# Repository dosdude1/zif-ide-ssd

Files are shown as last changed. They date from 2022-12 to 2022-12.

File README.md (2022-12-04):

# ZIF IDE SSD

A custom-designed IDE SSD for use in any machine that utilizies a 1.8" ZIF IDE hard disk. 

The design is based on the Silicon Motion SM2236 controller, and is compatible with up to four 512Gbit (64GB) BGA152 or BGA132 NANDs.

## Important Info

WARNING: THE SILICON MOTION SM2236 CONTROLLER PINOUT AND IMPLEMENTATION HAVE BEEN REVERSE ENGINEERED FROM OPEN DOCUMENTS AND SALVAGED PCBS, ALL OF WHICH HAVE BEEN LEGALLY OBTAINED. DO NOT EXPECT THIS TO BE CORRECT, CHECK FOR YOURSELF.

### NAND Info

- The NAND ICs used on this PCB must be explicitly supported by the SM2236 controller. All supported NAND ICs are listed in the SM2236 MPTool, or "Mass Production Tool". Be sure to verify compatibility before installing NANDs.

- All installed NAND ICs must match.

- Check the datasheet for your desired NAND ICs to determine their rated I/O voltage, and populate the correct resistor position on the board to set either 3.3V or 1.8V. This is shown in the schematic diagram.

## Programming

Upon the completion of board assembly, the SM2236 controller must be programmed for the NAND ICs you have installed. To do so, you must utilize an IDE to USB adapter to connect the drive to a PC running Windows (using native IDE for this will not work). Then, the SM2236 MPTool must be used to set all the desired drive information, select the part number of NAND ICs you have installed, and program the drive.

## 3D Printed Case

In the `Case` directory you will find an OpenSCAD file to produce a case for the SSD. This has been tuned to prusaslicer with:

- PETG filament

- Monotonic solid infill

- 0.35mm layer height

- 3 perimiters

It has not been printed under any other conditions. Because the case is only 8 layers thick it is very susceptible to poor bed adhesion and warping.

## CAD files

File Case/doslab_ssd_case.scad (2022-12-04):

// Created By: LogoiLab
// https://doslabelectronics.com/
// https://github.com/LogoiLab
// LICENSE: GPL-3.0
// UNITS: mm
$fn = $preview ? 32 : 100;

$board_thickness = 1;
$board_width = 50;
$board_height = 68;
$case_width = 54;
$case_height = 71;
$case_thickness = 5;
$top_components_thickness = 1.32;
$bottom_components_thickness = 0.5;
total_board_thickness = $board_thickness + $top_components_thickness + $bottom_components_thickness + 0.8;
//total_board_thickness = 2.7;

echo(total_board_thickness);

body(true);
translate([55,0,0]) rotate([180,0,0]) body(false);

module body(main) {
    difference() {
        translate([0,0,0]) cube([$case_width, $case_height, $case_thickness], center = true);
        if(main) {
            translate([0,0,($case_thickness/2)]) cube([$case_width, $case_height, $case_thickness], center = true);
            //chamfer();
        } else {
            //rotate([0,180,0]) chamfer();
            translate([0,0,-($case_thickness/2)+1]) cube([$case_width, $case_height, $case_thickness], center = true);
            translate([1,32,0]) cube([23.5,8,10], center=true);
            translate([17,31.5,3]) #cylinder(4,1,1, center=true);
        }
        pcb();
        //scale([1.01,1.01,1]) translate([0,1.3,0]) linear_extrude(height = total_board_thickness, convexity = 10, center = true) import ("./IDE-SSD-ZIF-brd.svg", center = true);
        if (main) {
            holes(total_board_thickness);
        } else {
            holes(total_board_thickness * 3);
        }
    }
}

module holes(depth) {
    translate([24.5,28,0]) #cylinder(depth,0.75,0.75,center=true);
    rotate([0,180,0]) {
        translate([24.5,28,0]) #cylinder(depth,0.75,0.75,center=true);
    }
    translate([0,2,0]) rotate([180,0,0]) {
        translate([24.5,27.5,0]) #cylinder(depth,0.7,0.75,center=true);
        rotate([0,180,0]) {
            translate([24.5,27.5,0]) #cylinder(depth,0.75,0.75,center=true);
        }
    }
}

module chamfer() {
    translate([-($case_width/2) + 1,0,0]) difference() {
        cube([2, $case_height, $case_thickness], center = true);
        translate([0,0,1]) cube([$case_width, $case_height, $case_thickness], center = true);
    }
    translate([$case_width/2 - 1,0,0]) difference() {
        cube([2, $case_height, $case_thickness], center = true);
        translate([0,0,1]) cube([$case_width, $case_height, $case_thickness], center = true);
    }
}

module pcb() {
    difference() {
        union() {
        cube([$board_width,$board_height,total_board_thickness], center=true);
        translate([1,3,0]) cube([23.5,$board_height+3,total_board_thickness], center=true);
        }
        translate([24.5,28,0]) cube([3,3,total_board_thickness],center=true);
        rotate([0,180,0]) {
            translate([24.5,28,0]) cube([3,3,total_board_thickness],center=true);
        }
        translate([0,2,0]) rotate([180,0,0]) {
            translate([24.5,27.5,0]) cube([3,3,total_board_thickness],center=true);
            rotate([0,180,0]) {
                translate([24.5,27.5,0]) cube([3,3,total_board_thickness],center=true);
            }
        }
    }
}

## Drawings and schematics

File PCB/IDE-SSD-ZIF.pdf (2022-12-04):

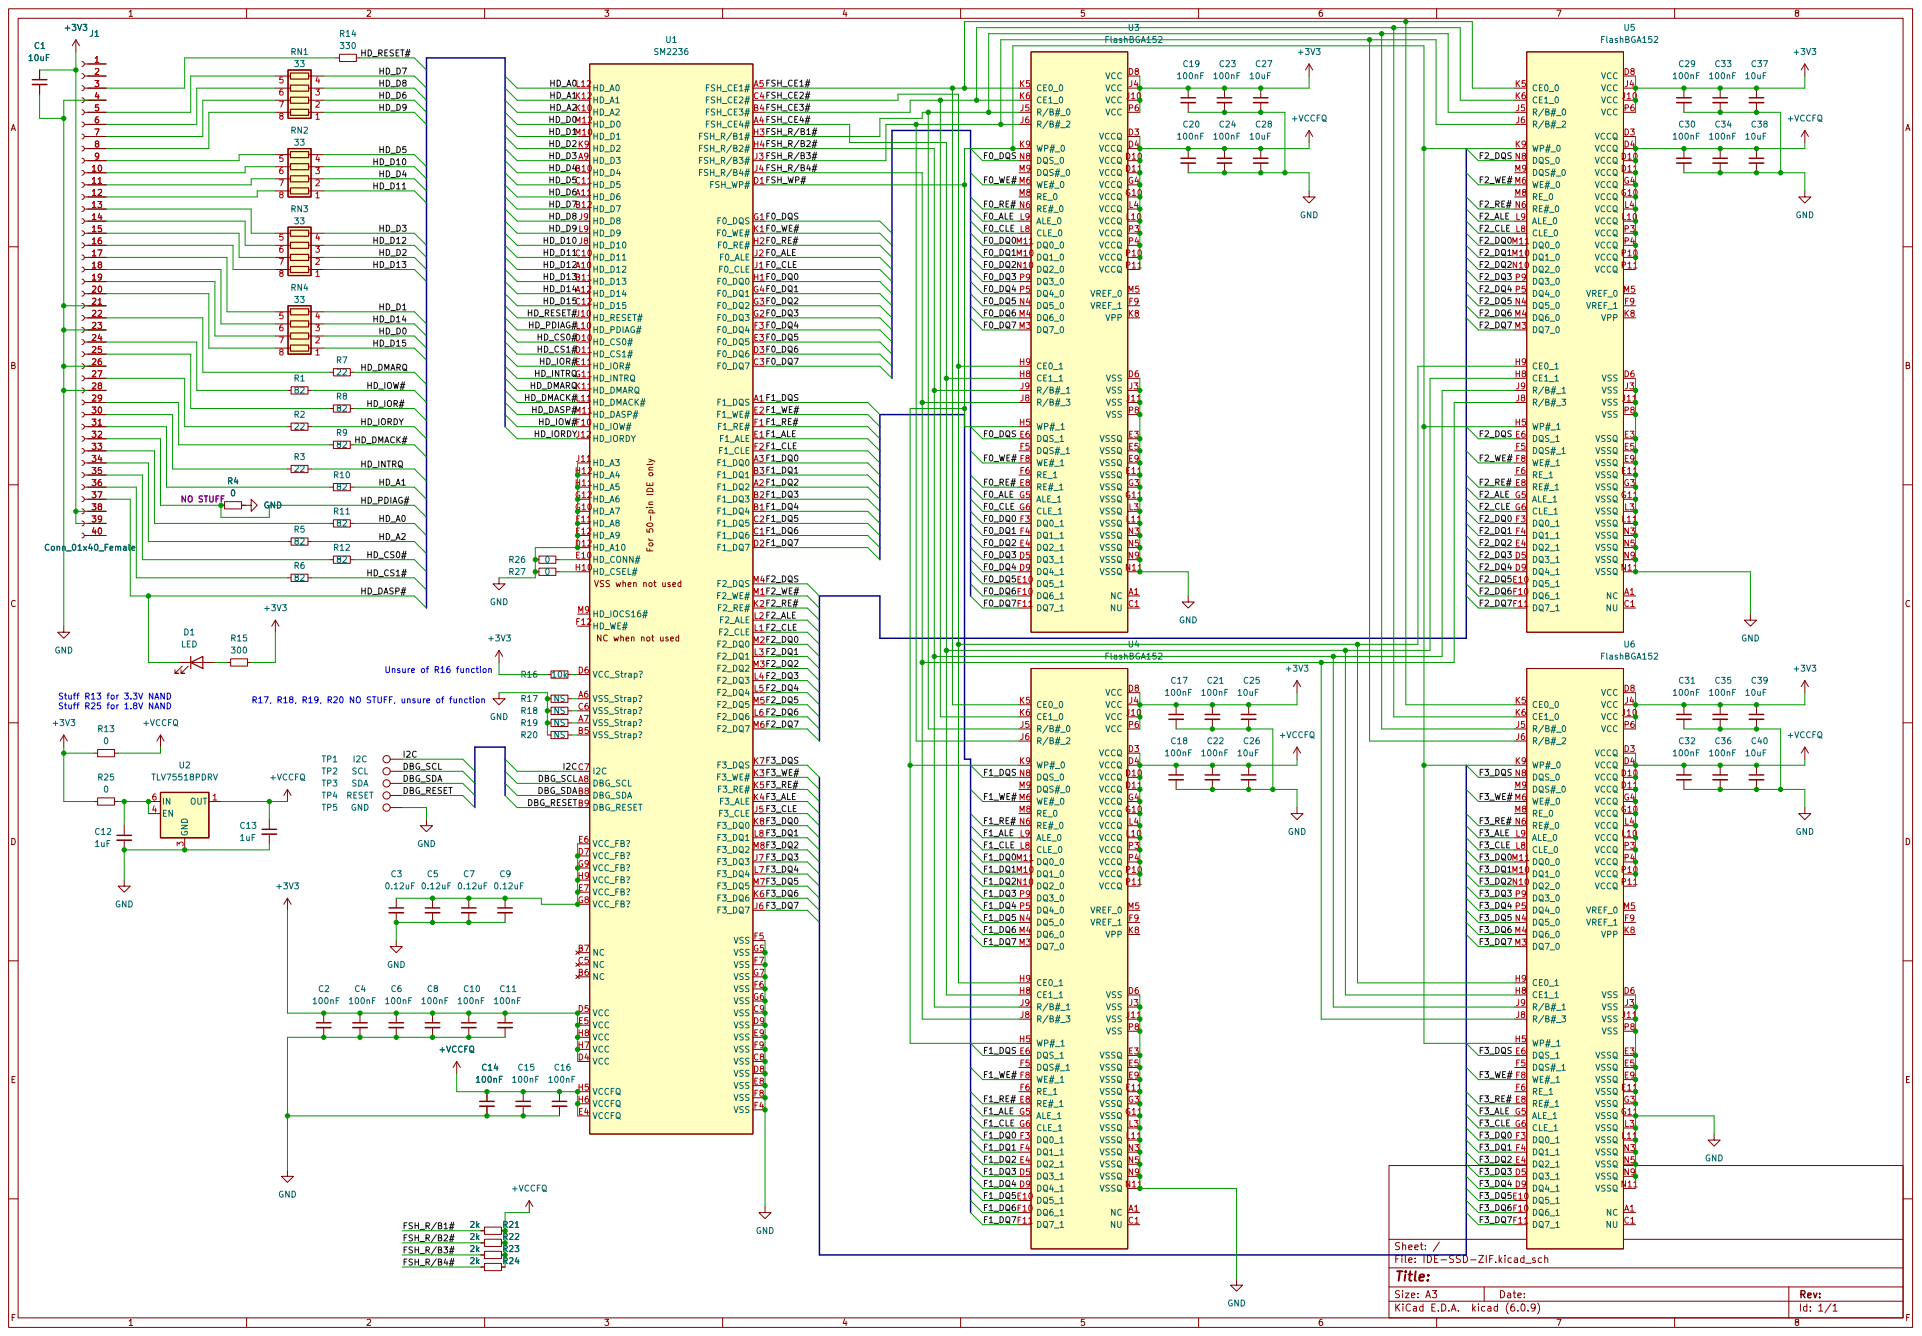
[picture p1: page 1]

File: IDE-SSD-ZIF.kicad_sch Sheet: / GND

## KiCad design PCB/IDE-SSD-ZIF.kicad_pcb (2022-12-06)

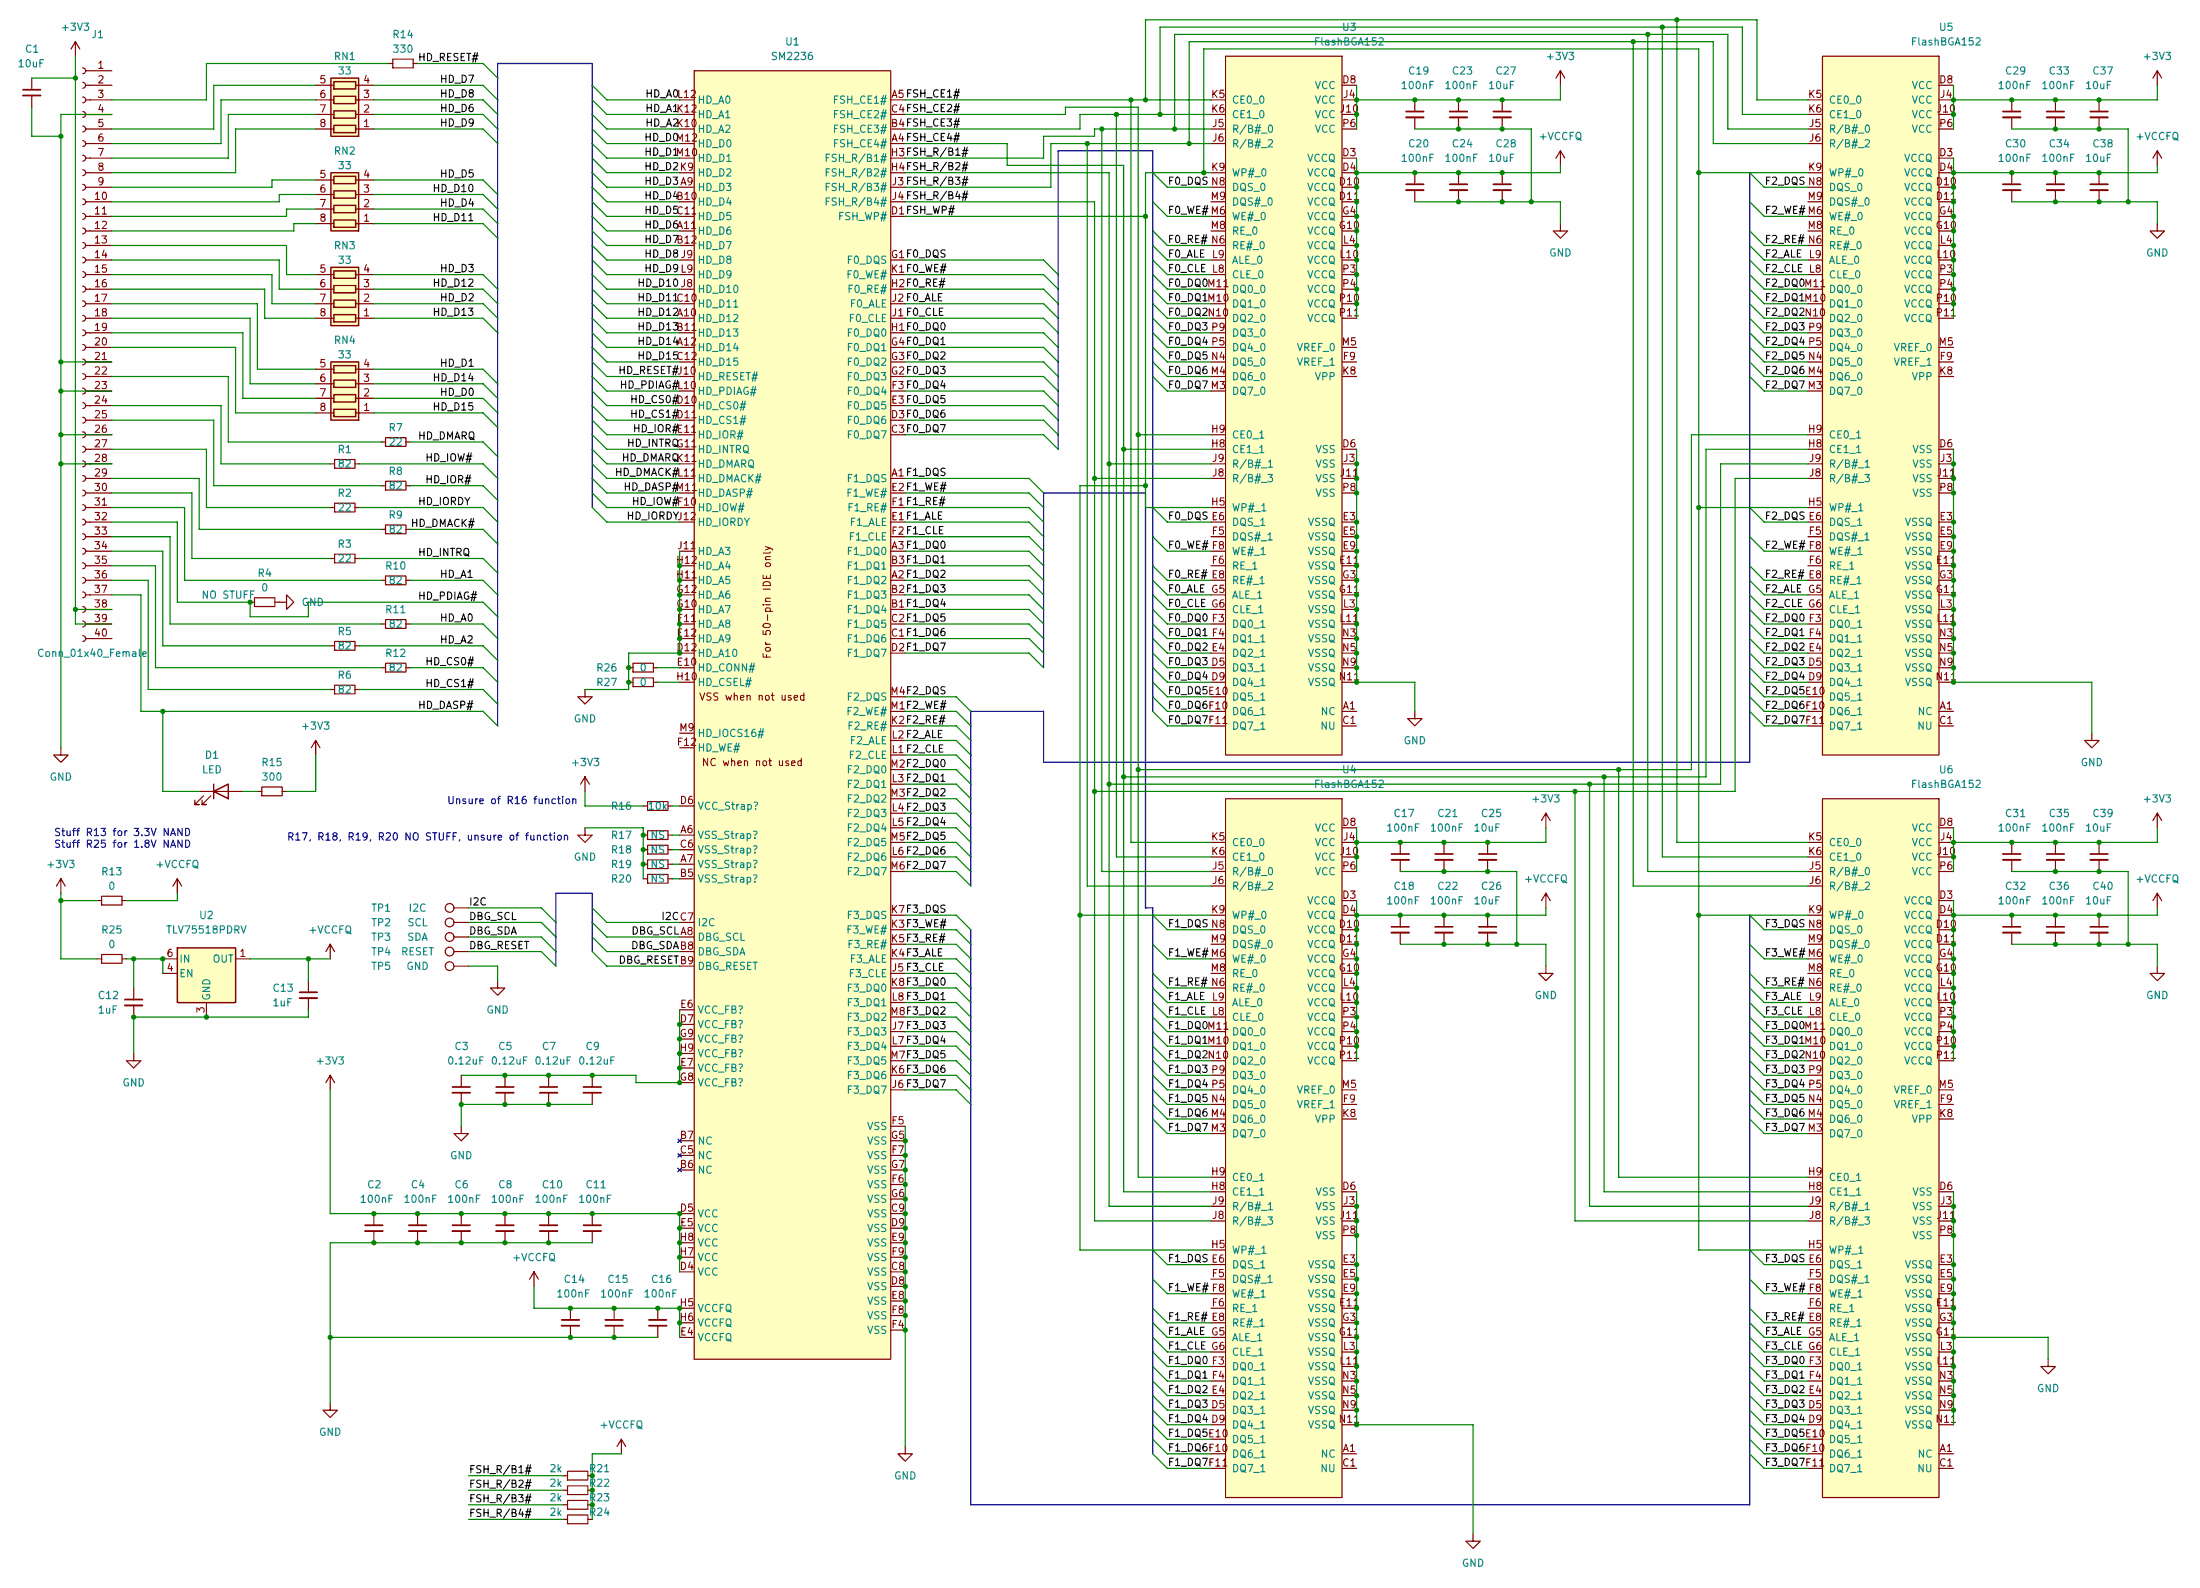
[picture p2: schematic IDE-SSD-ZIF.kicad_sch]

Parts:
C1: 10uF; C_0805_2012Metric
C2, C4, C6, C8, C10, C11, C14, C15, C16, C17, C18, C19, C20, C21, C22, C23, C24, C29, C30, C31, C32, C33, C34, C35, C36: 100nF; C_0402_1005Metric
C3, C5, C7, C9: 0.12uF; C_0402_1005Metric
C12, C13: 1uF; C_0603_1608Metric
C25, C26, C27, C28, C37, C38, C39, C40: 10uF; C_0603_1608Metric
D1: LED; LED_0603_1608Metric
J1: Conn_01x40_Female; OMRON_XF2U-4015-3A
R1, R5, R6, R8, R9, R10, R11, R12: 82; R_0402_1005Metric
R2, R3, R7: 22; R_0402_1005Metric
R4, R26, R27: 0; R_0402_1005Metric
R13, R25: 0; R_0603_1608Metric
R14: 330; R_0402_1005Metric
R15: 300; R_0402_1005Metric
R16: 10k; R_0402_1005Metric
R17, R18, R19, R20: NS; R_0402_1005Metric
R21, R22, R23, R24: 2k; R_0402_1005Metric
RN1, RN2, RN3, RN4: 33; R_Array_Convex_4x0402
TP1: I2C; TestPoint_Pad_1.0x1.0mm
TP2: SCL; TestPoint_Pad_1.0x1.0mm
TP3: SDA; TestPoint_Pad_1.0x1.0mm
TP4: RESET; TestPoint_Pad_1.0x1.0mm
TP5: GND; TestPoint_Pad_1.0x1.0mm
U1: SM2236; BGA-144_12x12_9.0x9.0mm
U2: TLV75518PDRV; WSON-6-1EP_2x2mm_P0.65mm_EP1x1.6mm
U3, U4, U5, U6: FlashBGA152; BGA-152_14x18mm_Layout13x17_P0.5mm

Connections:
+3V3: C1.1, C2.1, C4.1, C6.1, C8.1, C10.1, C11.1, C17.1, C19.1, C21.1, C23.1, C25.1, C27.1, C29.1, C31.1, C33.1, C35.1, C37.1, C39.1, J1.38, J1.39, R13.1, R15.2, R16.1, R25.1, U1.D4 (VCC), U1.D5 (VCC), U1.E5 (VCC), U1.H7 (VCC), U1.H8 (VCC), U3.D8 (VCC), U3.J4 (VCC), U3.J10 (VCC), U3.P6 (VCC), U4.D8 (VCC), U4.J4 (VCC), U4.J10 (VCC), U4.P6 (VCC), U5.D8 (VCC), U5.J4 (VCC), U5.J10 (VCC), U5.P6 (VCC), U6.D8 (VCC), U6.J4 (VCC), U6.J10 (VCC), U6.P6 (VCC)
+VCCFQ: C13.1, C14.1, C15.1, C16.1, C18.1, C20.1, C22.1, C24.1, C26.1, C28.1, C30.1, C32.1, C34.1, C36.1, C38.1, C40.1, R13.2, R21.2, R22.2, R23.2, R24.2, U1.E4 (VCCFQ), U1.H5 (VCCFQ), U1.H6 (VCCFQ), U2.1 (OUT), U3.D3 (VCCQ), U3.D4 (VCCQ), U3.D10 (VCCQ), U3.D11 (VCCQ), U3.G4 (VCCQ), U3.G10 (VCCQ), U3.L4 (VCCQ), U3.L10 (VCCQ), U3.P3 (VCCQ), U3.P4 (VCCQ), U3.P10 (VCCQ), U3.P11 (VCCQ), U4.D3 (VCCQ), U4.D4 (VCCQ), U4.D10 (VCCQ), U4.D11 (VCCQ), U4.G4 (VCCQ), U4.G10 (VCCQ), U4.L4 (VCCQ), U4.L10 (VCCQ), U4.P3 (VCCQ), U4.P4 (VCCQ), U4.P10 (VCCQ), U4.P11 (VCCQ), U5.D3 (VCCQ), U5.D4 (VCCQ), U5.D10 (VCCQ), U5.D11 (VCCQ), U5.G4 (VCCQ), U5.G10 (VCCQ), U5.L4 (VCCQ), U5.L10 (VCCQ), U5.P3 (VCCQ), U5.P4 (VCCQ), U5.P10 (VCCQ), U5.P11 (VCCQ), U6.D3 (VCCQ), U6.D4 (VCCQ), U6.D10 (VCCQ), U6.D11 (VCCQ), U6.G4 (VCCQ), U6.G10 (VCCQ), U6.L4 (VCCQ), U6.L10 (VCCQ), U6.P3 (VCCQ), U6.P4 (VCCQ), U6.P10 (VCCQ), U6.P11 (VCCQ)
/DBG_RESET: TP4.1, U1.B9 (DBG_RESET); also elsewhere on the board
/DBG_SCL: TP2.1, U1.A8 (DBG_SCL); also elsewhere on the board
/DBG_SDA: TP3.1, U1.B8 (DBG_SDA); also elsewhere on the board
/F0_ALE: U1.J2 (F0_ALE), U3.G5 (ALE_1), U3.L9 (ALE_0)
/F0_CLE: U1.J1 (F0_CLE), U3.G6 (CLE_1), U3.L8 (CLE_0)
/F0_DQ0: U1.H1 (F0_DQ0), U3.F3 (DQ0_1), U3.M11 (DQ0_0)
/F0_DQ1: U1.G4 (F0_DQ1), U3.F4 (DQ1_1), U3.M10 (DQ1_0)
/F0_DQ2: U1.G3 (F0_DQ2), U3.E4 (DQ2_1), U3.N10 (DQ2_0)
/F0_DQ3: U1.G2 (F0_DQ3), U3.D5 (DQ3_1), U3.P9 (DQ3_0)
/F0_DQ4: U1.F3 (F0_DQ4), U3.D9 (DQ4_1), U3.P5 (DQ4_0)
/F0_DQ5: U1.E3 (F0_DQ5), U3.E10 (DQ5_1), U3.N4 (DQ5_0)
/F0_DQ6: U1.D3 (F0_DQ6), U3.F10 (DQ6_1), U3.M4 (DQ6_0)
/F0_DQ7: U1.C3 (F0_DQ7), U3.F11 (DQ7_1), U3.M3 (DQ7_0)
/F0_DQS: U1.G1 (F0_DQS), U3.E6 (DQS_1), U3.N8 (DQS_0)
/F0_RE#: U1.H2 (F0_RE#), U3.E8 (RE#_1), U3.N6 (RE#_0)
/F0_WE#: U1.K1 (F0_WE#), U3.F8 (WE#_1), U3.M6 (WE#_0)
/F1_ALE: U1.E1 (F1_ALE), U4.G5 (ALE_1), U4.L9 (ALE_0)
/F1_CLE: U1.F2 (F1_CLE), U4.G6 (CLE_1), U4.L8 (CLE_0)
/F1_DQ0: U1.A3 (F1_DQ0), U4.F3 (DQ0_1), U4.M11 (DQ0_0)
/F1_DQ1: U1.B3 (F1_DQ1), U4.F4 (DQ1_1), U4.M10 (DQ1_0)
/F1_DQ2: U1.A2 (F1_DQ2), U4.E4 (DQ2_1), U4.N10 (DQ2_0)
/F1_DQ3: U1.B2 (F1_DQ3), U4.D5 (DQ3_1), U4.P9 (DQ3_0)
/F1_DQ4: U1.B1 (F1_DQ4), U4.D9 (DQ4_1), U4.P5 (DQ4_0)
/F1_DQ5: U1.C2 (F1_DQ5), U4.E10 (DQ5_1), U4.N4 (DQ5_0)
/F1_DQ6: U1.C1 (F1_DQ6), U4.F10 (DQ6_1), U4.M4 (DQ6_0)
/F1_DQ7: U1.D2 (F1_DQ7), U4.F11 (DQ7_1), U4.M3 (DQ7_0)
/F1_DQS: U1.A1 (F1_DQS), U4.E6 (DQS_1), U4.N8 (DQS_0)
/F1_RE#: U1.F1 (F1_RE#), U4.E8 (RE#_1), U4.N6 (RE#_0)
/F1_WE#: U1.E2 (F1_WE#), U4.F8 (WE#_1), U4.M6 (WE#_0)
/F2_ALE: U1.L2 (F2_ALE), U5.G5 (ALE_1), U5.L9 (ALE_0)
/F2_CLE: U1.L1 (F2_CLE), U5.G6 (CLE_1), U5.L8 (CLE_0)
/F2_DQ0: U1.M2 (F2_DQ0), U5.F3 (DQ0_1), U5.M11 (DQ0_0)
/F2_DQ1: U1.L3 (F2_DQ1), U5.F4 (DQ1_1), U5.M10 (DQ1_0)
/F2_DQ2: U1.M3 (F2_DQ2), U5.E4 (DQ2_1), U5.N10 (DQ2_0)
/F2_DQ3: U1.L4 (F2_DQ3), U5.D5 (DQ3_1), U5.P9 (DQ3_0)
/F2_DQ4: U1.L5 (F2_DQ4), U5.D9 (DQ4_1), U5.P5 (DQ4_0)
/F2_DQ5: U1.M5 (F2_DQ5), U5.E10 (DQ5_1), U5.N4 (DQ5_0)
/F2_DQ6: U1.L6 (F2_DQ6), U5.F10 (DQ6_1), U5.M4 (DQ6_0)
/F2_DQ7: U1.M6 (F2_DQ7), U5.F11 (DQ7_1), U5.M3 (DQ7_0)
/F2_DQS: U1.M4 (F2_DQS), U5.E6 (DQS_1), U5.N8 (DQS_0)
/F2_RE#: U1.K2 (F2_RE#), U5.E8 (RE#_1), U5.N6 (RE#_0)
/F2_WE#: U1.M1 (F2_WE#), U5.F8 (WE#_1), U5.M6 (WE#_0)
/F3_ALE: U1.K4 (F3_ALE), U6.G5 (ALE_1), U6.L9 (ALE_0)
/F3_CLE: U1.J5 (F3_CLE), U6.G6 (CLE_1), U6.L8 (CLE_0)
/F3_DQ0: U1.K8 (F3_DQ0), U6.F3 (DQ0_1), U6.M11 (DQ0_0)
/F3_DQ1: U1.L8 (F3_DQ1), U6.F4 (DQ1_1), U6.M10 (DQ1_0)
/F3_DQ2: U1.M8 (F3_DQ2), U6.E4 (DQ2_1), U6.N10 (DQ2_0)
/F3_DQ3: U1.J7 (F3_DQ3), U6.D5 (DQ3_1), U6.P9 (DQ3_0)
/F3_DQ4: U1.L7 (F3_DQ4), U6.D9 (DQ4_1), U6.P5 (DQ4_0)
/F3_DQ5: U1.M7 (F3_DQ5), U6.E10 (DQ5_1), U6.N4 (DQ5_0)
/F3_DQ6: U1.K6 (F3_DQ6), U6.F10 (DQ6_1), U6.M4 (DQ6_0)
/F3_DQ7: U1.J6 (F3_DQ7), U6.F11 (DQ7_1), U6.M3 (DQ7_0)
/F3_DQS: U1.K7 (F3_DQS), U6.E6 (DQS_1), U6.N8 (DQS_0)
/F3_RE#: U1.K5 (F3_RE#), U6.E8 (RE#_1), U6.N6 (RE#_0)
/F3_WE#: U1.K3 (F3_WE#), U6.F8 (WE#_1), U6.M6 (WE#_0)
/FSH_CE1#: U1.A5 (FSH_CE1#), U3.K5 (CE0_0), U4.K5 (CE0_0), U5.K5 (CE0_0), U6.K5 (CE0_0)
/FSH_CE2#: U1.C4 (FSH_CE2#), U3.H9 (CE0_1), U4.H9 (CE0_1), U5.H9 (CE0_1), U6.H9 (CE0_1)
/FSH_CE3#: U1.B4 (FSH_CE3#), U3.K6 (CE1_0), U4.K6 (CE1_0), U5.K6 (CE1_0), U6.K6 (CE1_0)
/FSH_CE4#: U1.A4 (FSH_CE4#), U3.H8 (CE1_1), U4.H8 (CE1_1), U5.H8 (CE1_1), U6.H8 (CE1_1)
/FSH_R/B1#: R21.1, U1.H3 (FSH_R/B1#), U3.J5 (R/B#_0), U4.J5 (R/B#_0), U5.J5 (R/B#_0), U6.J5 (R/B#_0)
/FSH_R/B2#: R22.1, U1.H4 (FSH_R/B2#), U3.J9 (R/B#_1), U4.J9 (R/B#_1), U5.J9 (R/B#_1), U6.J9 (R/B#_1)
/FSH_R/B3#: R23.1, U1.J3 (FSH_R/B3#), U3.J6 (R/B#_2), U4.J6 (R/B#_2), U5.J6 (R/B#_2), U6.J6 (R/B#_2)
/FSH_R/B4#: R24.1, U1.J4 (FSH_R/B4#), U3.J8 (R/B#_3), U4.J8 (R/B#_3), U5.J8 (R/B#_3), U6.J8 (R/B#_3)
/FSH_WP#: U1.D1 (FSH_WP#), U3.H5 (WP#_1), U3.K9 (WP#_0), U4.H5 (WP#_1), U4.K9 (WP#_0), U5.H5 (WP#_1), U5.K9 (WP#_0), U6.H5 (WP#_1), U6.K9 (WP#_0)
/HD_A0: R11.2, U1.L12 (HD_A0)
/HD_A1: R10.2, U1.K12 (HD_A1)
/HD_A2: R5.2, U1.K10 (HD_A2)
/HD_CS0#: R12.2, U1.D10 (HD_CS0#)
/HD_CS1#: R6.2, U1.D11 (HD_CS1#)
/HD_D0: RN4.2 (R2.1), U1.M12 (HD_D0)
/HD_D1: RN4.4 (R4.1), U1.M10 (HD_D1)
/HD_D2: RN3.2 (R2.1), U1.K9 (HD_D2)
/HD_D3: RN3.4 (R4.1), U1.A9 (HD_D3)
/HD_D4: RN2.2 (R2.1), U1.B10 (HD_D4)
/HD_D5: RN2.4 (R4.1), U1.C11 (HD_D5)
/HD_D6: RN1.2 (R2.1), U1.A11 (HD_D6)
/HD_D7: RN1.4 (R4.1), U1.B12 (HD_D7)
/HD_D8: RN1.3 (R3.1), U1.J9 (HD_D8)
/HD_D9: RN1.1 (R1.1), U1.L9 (HD_D9)
/HD_D10: RN2.3 (R3.1), U1.J8 (HD_D10)
/HD_D11: RN2.1 (R1.1), U1.C10 (HD_D11)
/HD_D12: RN3.3 (R3.1), U1.A10 (HD_D12)
/HD_D13: RN3.1 (R1.1), U1.B11 (HD_D13)
/HD_D14: RN4.3 (R3.1), U1.A12 (HD_D14)
/HD_D15: RN4.1 (R1.1), U1.C12 (HD_D15)
/HD_DASP#: D1.1 (K), J1.37, U1.M11 (HD_DASP#)
/HD_DMACK#: R9.2, U1.L11 (HD_DMACK#)
/HD_DMARQ: R7.2, U1.K11 (HD_DMARQ)
/HD_INTRQ: R3.2, U1.G11 (HD_INTRQ)
/HD_IOR#: R8.2, U1.E11 (HD_IOR#)
/HD_IORDY: R2.2, U1.J12 (HD_IORDY)
/HD_IOW#: R1.2, U1.F10 (HD_IOW#)
/HD_PDIAG#: J1.32, R4.1, U1.L10 (HD_PDIAG#)
/HD_RESET#: R14.2, U1.J10 (HD_RESET#)
/I2C: TP1.1, U1.C7 (I2C); also elsewhere on the board
GND: C1.2, C2.2, C3.2, C4.2, C5.2, C6.2, C7.2, C8.2, C9.2, C10.2, C11.2, C12.2, C13.2, C14.2, C15.2, C16.2, C17.2, C18.2, C19.2, C20.2, C21.2, C22.2, C23.2, C24.2, C25.2, C26.2, C27.2, C28.2, C29.2, C30.2, C31.2, C32.2, C33.2, C34.2, C35.2, C36.2, C37.2, C38.2, C39.2, C40.2, J1.4, J1.21, J1.23, J1.26, J1.28, R4.2, R17.1, R18.1, R19.1, R20.1, R26.1, R27.1, TP5.1, U1.C8 (VSS), U1.C9 (VSS), U1.D8 (VSS), U1.D9 (VSS), U1.D12 (HD_A10), U1.E8 (VSS), U1.E9 (VSS), U1.E12 (HD_A9), U1.F4 (VSS), U1.F5 (VSS), U1.F6 (VSS), U1.F7 (VSS), U1.F8 (VSS), U1.F9 (VSS), U1.F11 (HD_A8), U1.G5 (VSS), U1.G6 (VSS), U1.G7 (VSS), U1.G10 (HD_A7), U1.G12 (HD_A6), U1.H11 (HD_A5), U1.H12 (HD_A4), U1.J11 (HD_A3), U2.3 (GND), U2.7 (GND), U3.D6 (VSS), U3.E3 (VSSQ), U3.E5 (VSSQ), U3.E9 (VSSQ), U3.E11 (VSSQ), U3.G3 (VSSQ), U3.G11 (VSSQ), U3.J3 (VSS), U3.J11 (VSS), U3.L3 (VSSQ), U3.L11 (VSSQ), U3.N3 (VSSQ), U3.N5 (VSSQ), U3.N9 (VSSQ), U3.N11 (VSSQ), U3.P8 (VSS), U4.D6 (VSS), U4.E3 (VSSQ), U4.E5 (VSSQ), U4.E9 (VSSQ), U4.E11 (VSSQ), U4.G3 (VSSQ), U4.G11 (VSSQ), U4.J3 (VSS), U4.J11 (VSS), U4.L3 (VSSQ), U4.L11 (VSSQ), U4.N3 (VSSQ), U4.N5 (VSSQ), U4.N9 (VSSQ), U4.N11 (VSSQ), U4.P8 (VSS), U5.D6 (VSS), U5.E3 (VSSQ), U5.E5 (VSSQ), U5.E9 (VSSQ), U5.E11 (VSSQ), U5.G3 (VSSQ), U5.G11 (VSSQ), U5.J3 (VSS), U5.J11 (VSS), U5.L3 (VSSQ), U5.L11 (VSSQ), U5.N3 (VSSQ), U5.N5 (VSSQ), U5.N9 (VSSQ), U5.N11 (VSSQ), U5.P8 (VSS), U6.D6 (VSS), U6.E3 (VSSQ), U6.E5 (VSSQ), U6.E9 (VSSQ), U6.E11 (VSSQ), U6.G3 (VSSQ), U6.G11 (VSSQ), U6.J3 (VSS), U6.J11 (VSS), U6.L3 (VSSQ), U6.L11 (VSSQ), U6.N3 (VSSQ), U6.N5 (VSSQ), U6.N9 (VSSQ), U6.N11 (VSSQ), U6.P8 (VSS); also elsewhere on the board
unnamed: C3.1, C5.1, C7.1, C9.1, U1.D7 (VCC_FB?), U1.E6 (VCC_FB?), U1.E7 (VCC_FB?), U1.G8 (VCC_FB?), U1.G9 (VCC_FB?), U1.H9 (VCC_FB?)
unnamed: C12.1, R25.2, U2.4 (EN), U2.6 (IN)
unnamed: D1.2 (A), R15.1
unnamed: J1.3, R14.1
unnamed: J1.5, RN1.5 (R4.2)
unnamed: J1.6, RN1.6 (R3.2)
unnamed: J1.7, RN1.7 (R2.2)
unnamed: J1.8, RN1.8 (R1.2)
unnamed: J1.9, RN2.5 (R4.2)
unnamed: J1.10, RN2.6 (R3.2)
unnamed: J1.11, RN2.7 (R2.2)
unnamed: J1.12, RN2.8 (R1.2)
unnamed: J1.13, RN3.5 (R4.2)
unnamed: J1.14, RN3.6 (R3.2)
unnamed: J1.15, RN3.7 (R2.2)
unnamed: J1.16, RN3.8 (R1.2)
unnamed: J1.17, RN4.5 (R4.2)
unnamed: J1.18, RN4.6 (R3.2)
unnamed: J1.19, RN4.7 (R2.2)
unnamed: J1.20, RN4.8 (R1.2)
unnamed: J1.22, R7.1
unnamed: J1.24, R1.1
unnamed: J1.25, R8.1
unnamed: J1.27, R2.1
unnamed: J1.29, R9.1
unnamed: J1.30, R3.1
unnamed: J1.31, R10.1
unnamed: J1.33, R11.1
unnamed: J1.34, R5.1
unnamed: J1.35, R12.1
unnamed: J1.36, R6.1
unnamed: R16.2, U1.D6 (VCC_Strap?)
unnamed: R17.2, U1.A6 (VSS_Strap?)
unnamed: R18.2, U1.C6 (VSS_Strap?)
unnamed: R19.2, U1.A7 (VSS_Strap?)
unnamed: R20.2, U1.B5 (VSS_Strap?)
unnamed: R26.2, U1.E10 (HD_CONN#)
unnamed: R27.2, U1.H10 (HD_CSEL#)

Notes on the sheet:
Stuff R13 for 3.3V NAND Stuff R25 for 1.8V NAND
Unsure of R16 function
R17, R18, R19, R20 NO STUFF, unsure of function

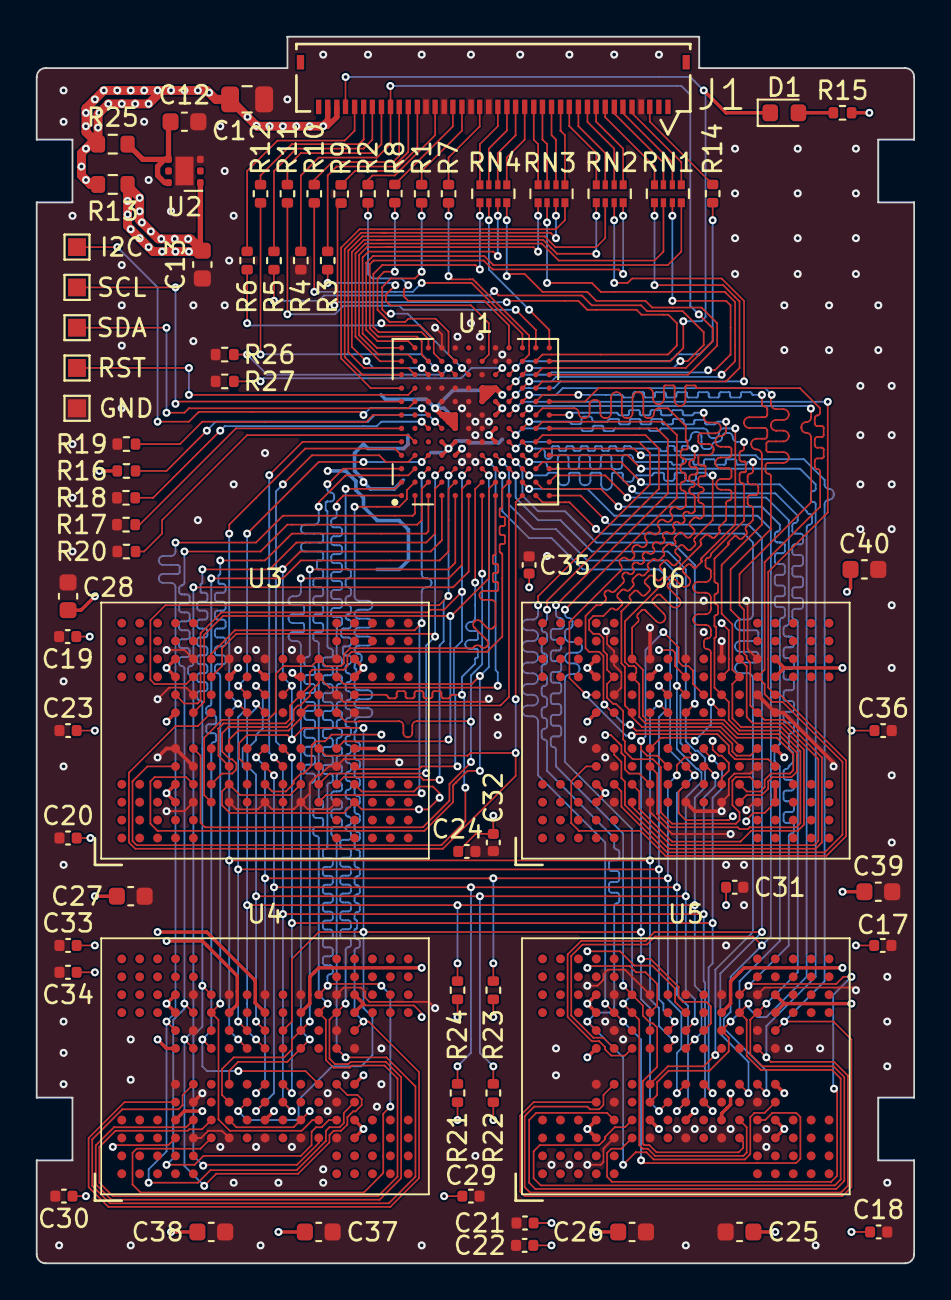
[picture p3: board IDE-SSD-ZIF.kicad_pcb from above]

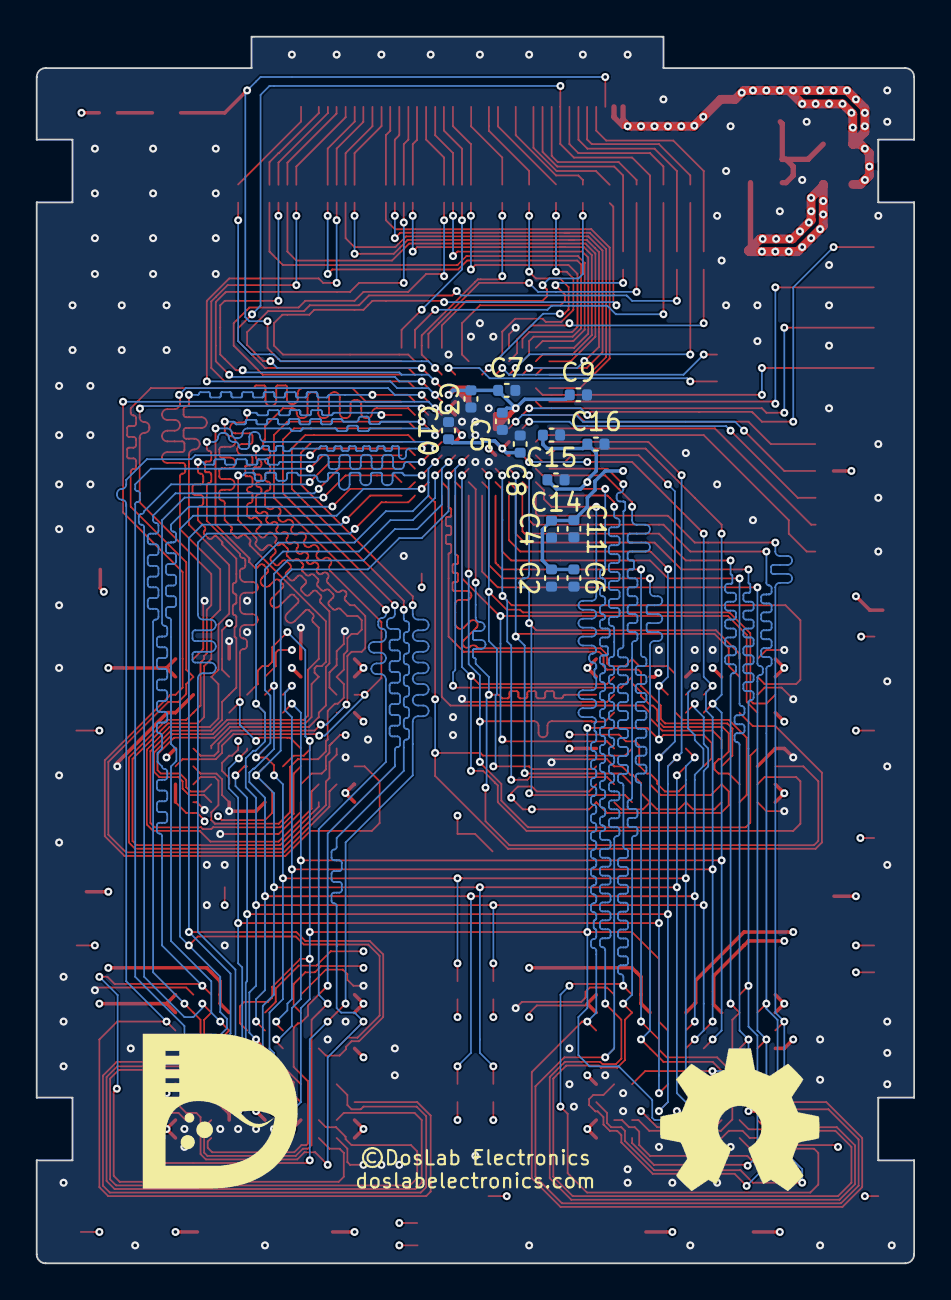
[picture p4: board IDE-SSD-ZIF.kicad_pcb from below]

Board: 4 copper layers, 49.0 x 68.5 mm, 84 parts (13 on the bottom side), 136 nets.

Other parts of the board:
GND: GND; TestPoint_Pad_1.0x1.0mm
I2C: I2C; TestPoint_Pad_1.0x1.0mm
RST: RESET; TestPoint_Pad_1.0x1.0mm
SCL: SCL; TestPoint_Pad_1.0x1.0mm
SDA: SDA; TestPoint_Pad_1.0x1.0mm

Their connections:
/DBG_RESET: RST.1; also elsewhere on the board
/DBG_SCL: SCL.1; also elsewhere on the board
/DBG_SDA: SDA.1; also elsewhere on the board
/I2C: I2C.1; also elsewhere on the board
GND: GND.1; also elsewhere on the board

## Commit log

2022-11-09 Updated PDF
    [IDE-SSD-ZIF-B_Cu.gbr, IDE-SSD-ZIF-B_Mask.gbr, IDE-SSD-ZIF-B_Paste.gbr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]
2022-11-09 added case and README section
2022-12-04 Changed 1.8V reg
    [IDE-SSD-ZIF.kicad_pcb, IDE-SSD-ZIF.kicad_sch]
2022-12-06 Fixed regulator footprint
    [IDE-SSD-ZIF.kicad_pcb, IDE-SSD-ZIF.kicad_sch]

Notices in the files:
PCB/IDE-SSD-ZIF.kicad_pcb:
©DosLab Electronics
